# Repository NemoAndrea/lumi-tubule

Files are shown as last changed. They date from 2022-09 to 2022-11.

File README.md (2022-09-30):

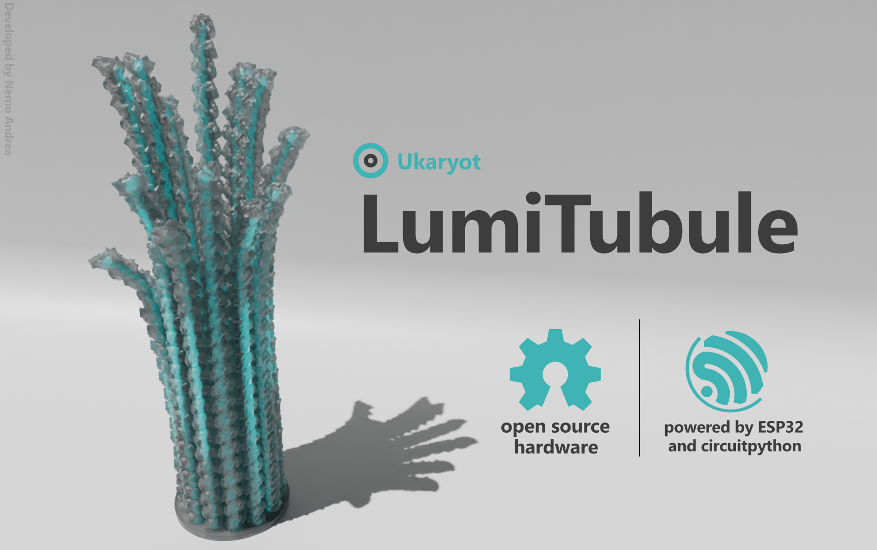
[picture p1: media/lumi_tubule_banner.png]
lumi tubule promo image


> **warning** 🚧 Under Construction - There is still a lot of work to be done on this project. Have a look at issues if you want to contribute (e.g. review PCB) or check back later when the project is getting closer to release 👷

## LumiTubule - open hardware decorative led sculpture

LumiTubule is a simple decorative lamp in the shape of a [microtubule]() that can be programmed to respond to events (e.g. emails). While primarily decorative, the PCB comes with a temperature and humidity sensor and a basic accelerometer for user interaction - and a stemma QT port in case you want to add more sensors!

It's all powered by a small USB-C power supply, so it barely takes up any desk space.

The PCB design, 3D printable files and bill of materials are all available, so you can put together your own LumiTubule. If you would like to have one, but would rather not go through the assembly process, you can get in touch. 

### Components

There are 4 key components that make up the LumiTubule

1. The custom PCB with ESP32 microcontroller and onboard sensors
2. A [15W USB-C power supply](https://www.raspberrypi.com/products/type-c-power-supply/)
3. The 3D printed microtubule sculpture (translucent)
4. The 13 flexible LED filaments that sit inside the sculpture

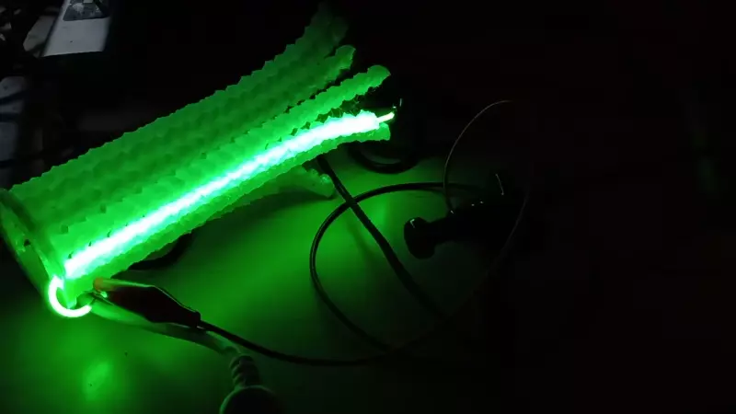
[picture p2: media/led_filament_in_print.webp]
led filaments in action


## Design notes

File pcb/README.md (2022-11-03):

### LumiTubule PCB

The LumiTubule PCB is generated with KiCad 6.0

The following plugins were used:

* [Teardrops plugin](https://github.com/NilujePerchut/kicad_scripts/tree/master/teardrops) (manual install - in PCBnew go to `tools` > `external plugins` > `open plugin directory`) 
* [Rounded tracks plugin](https://github.com/mitxela/kicad-round-tracks) (via plugin manager)

### Graphics

The graphics for the board are primarily created in Affinity Designer, with the help of [Inkscape](https://inkscape.org/) for some of the outline traces and image binarisation.

Some weird quirks during drawing process

- KiCad seems really picky about when it will render the hole in the board. The outline of the board has a lot of polygons. I am not sure what property of the inner circle makes it work better, but be aware that some frustrations may occur here if you try to change it.

### Considerations

> **Note** The points below provide some insight into why certain parts were selected. If you spot any errors in the calculations or reasoning, feel free to let me know!

**LED filament current limiting resistor value**

The LED filaments can handle about 100mA current (more in practice seems fine), so let's aim for that value. 

We start with a 5V supply.  These kind of LED filaments [have been reported to drop around 2.56V](https://www.brickstuff.com/store/p198/flexfilament.html), which is consistent with measurements done on a test rig. They seem to all use blue LEDs underneath, so that is a pretty safe maximum drop. The `DMN1045UFR4` MOSFET has a typical R_DSon between 25-32mΩ at 3.3V V_GS according to the datasheet. The voltage drop over the MOSFET will be 0.1A*25mΩ = 2.5mV. We can safely ignore that value. Our resistor value should then be (Vsup - V_LED)/I_LED = (5-2.56) / 0.1 = 24Ω. Let's play it safe and get something slightly higher: 27Ω. 

We then dissipate `P = I^2 * R  = 0.1^2 * 27 = 270mW` in the current limiting resistor. At max power on all 13 filaments this is 13*0.27=3.5W, quite a bit of power. Given that it is a worst-case scenario, it should be acceptable.

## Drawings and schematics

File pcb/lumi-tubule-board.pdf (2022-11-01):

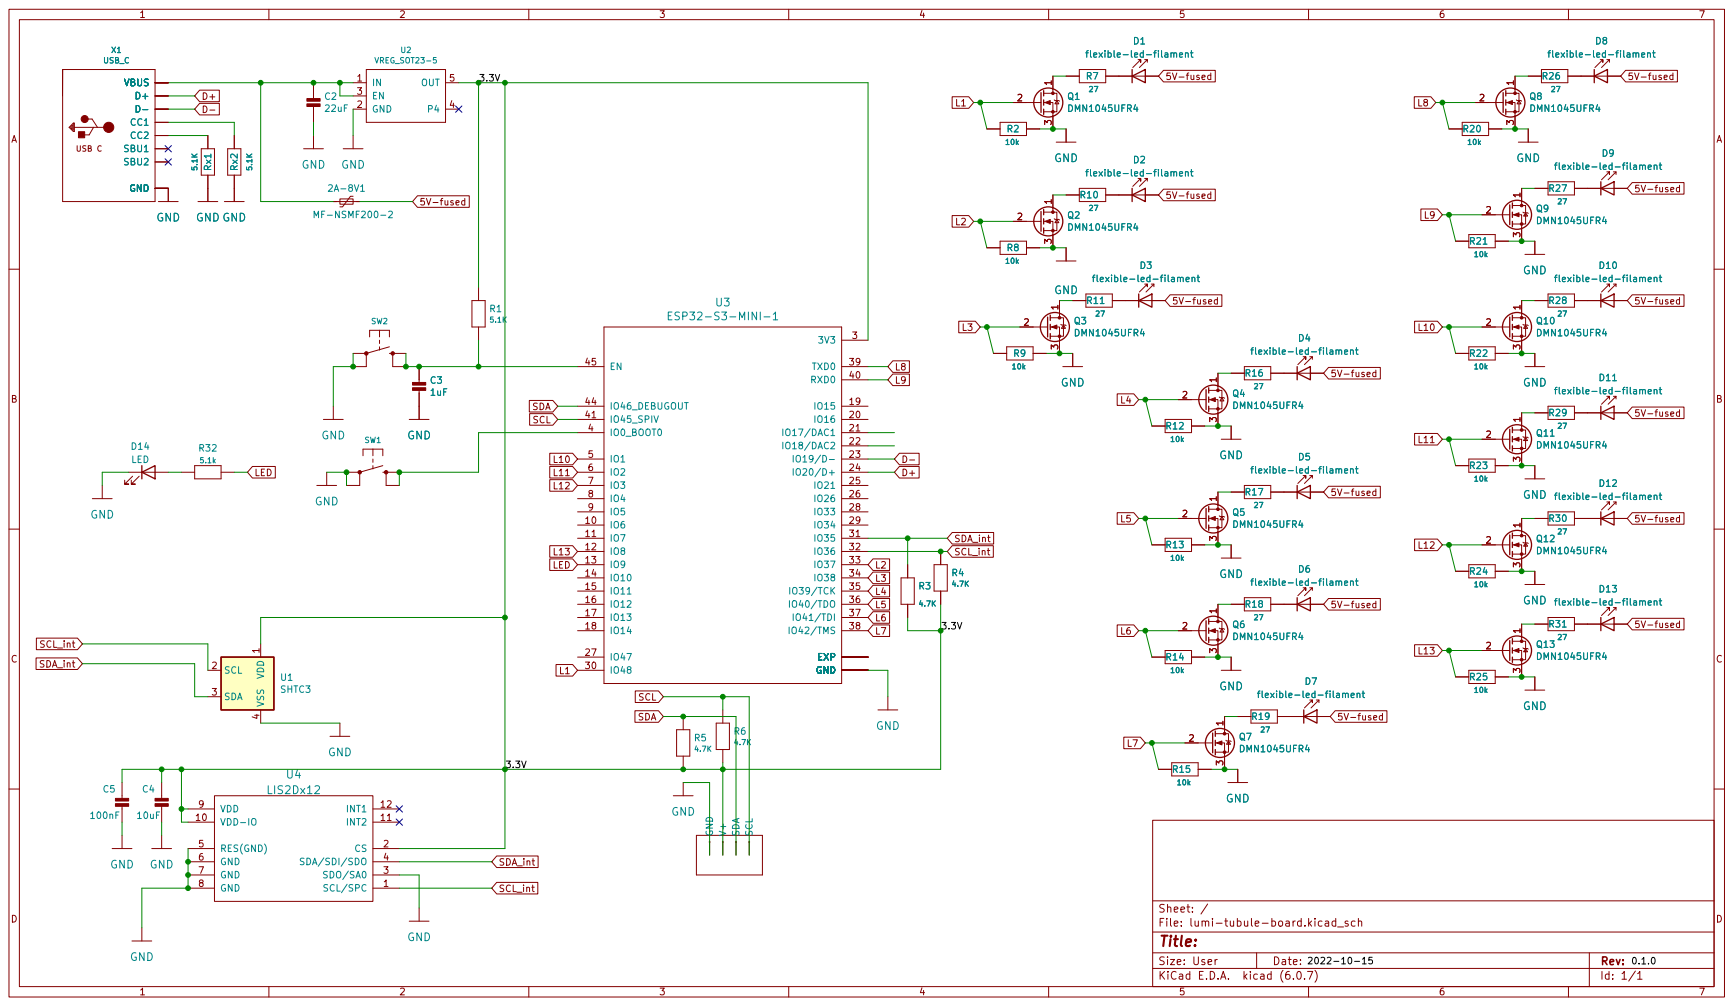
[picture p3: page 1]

flexible-led-filament VDD

3 Q11 DMN1045UFR4 GND D11
flexible-led-filament GND
flexible-led-filament R29

flexible-led-filament R17

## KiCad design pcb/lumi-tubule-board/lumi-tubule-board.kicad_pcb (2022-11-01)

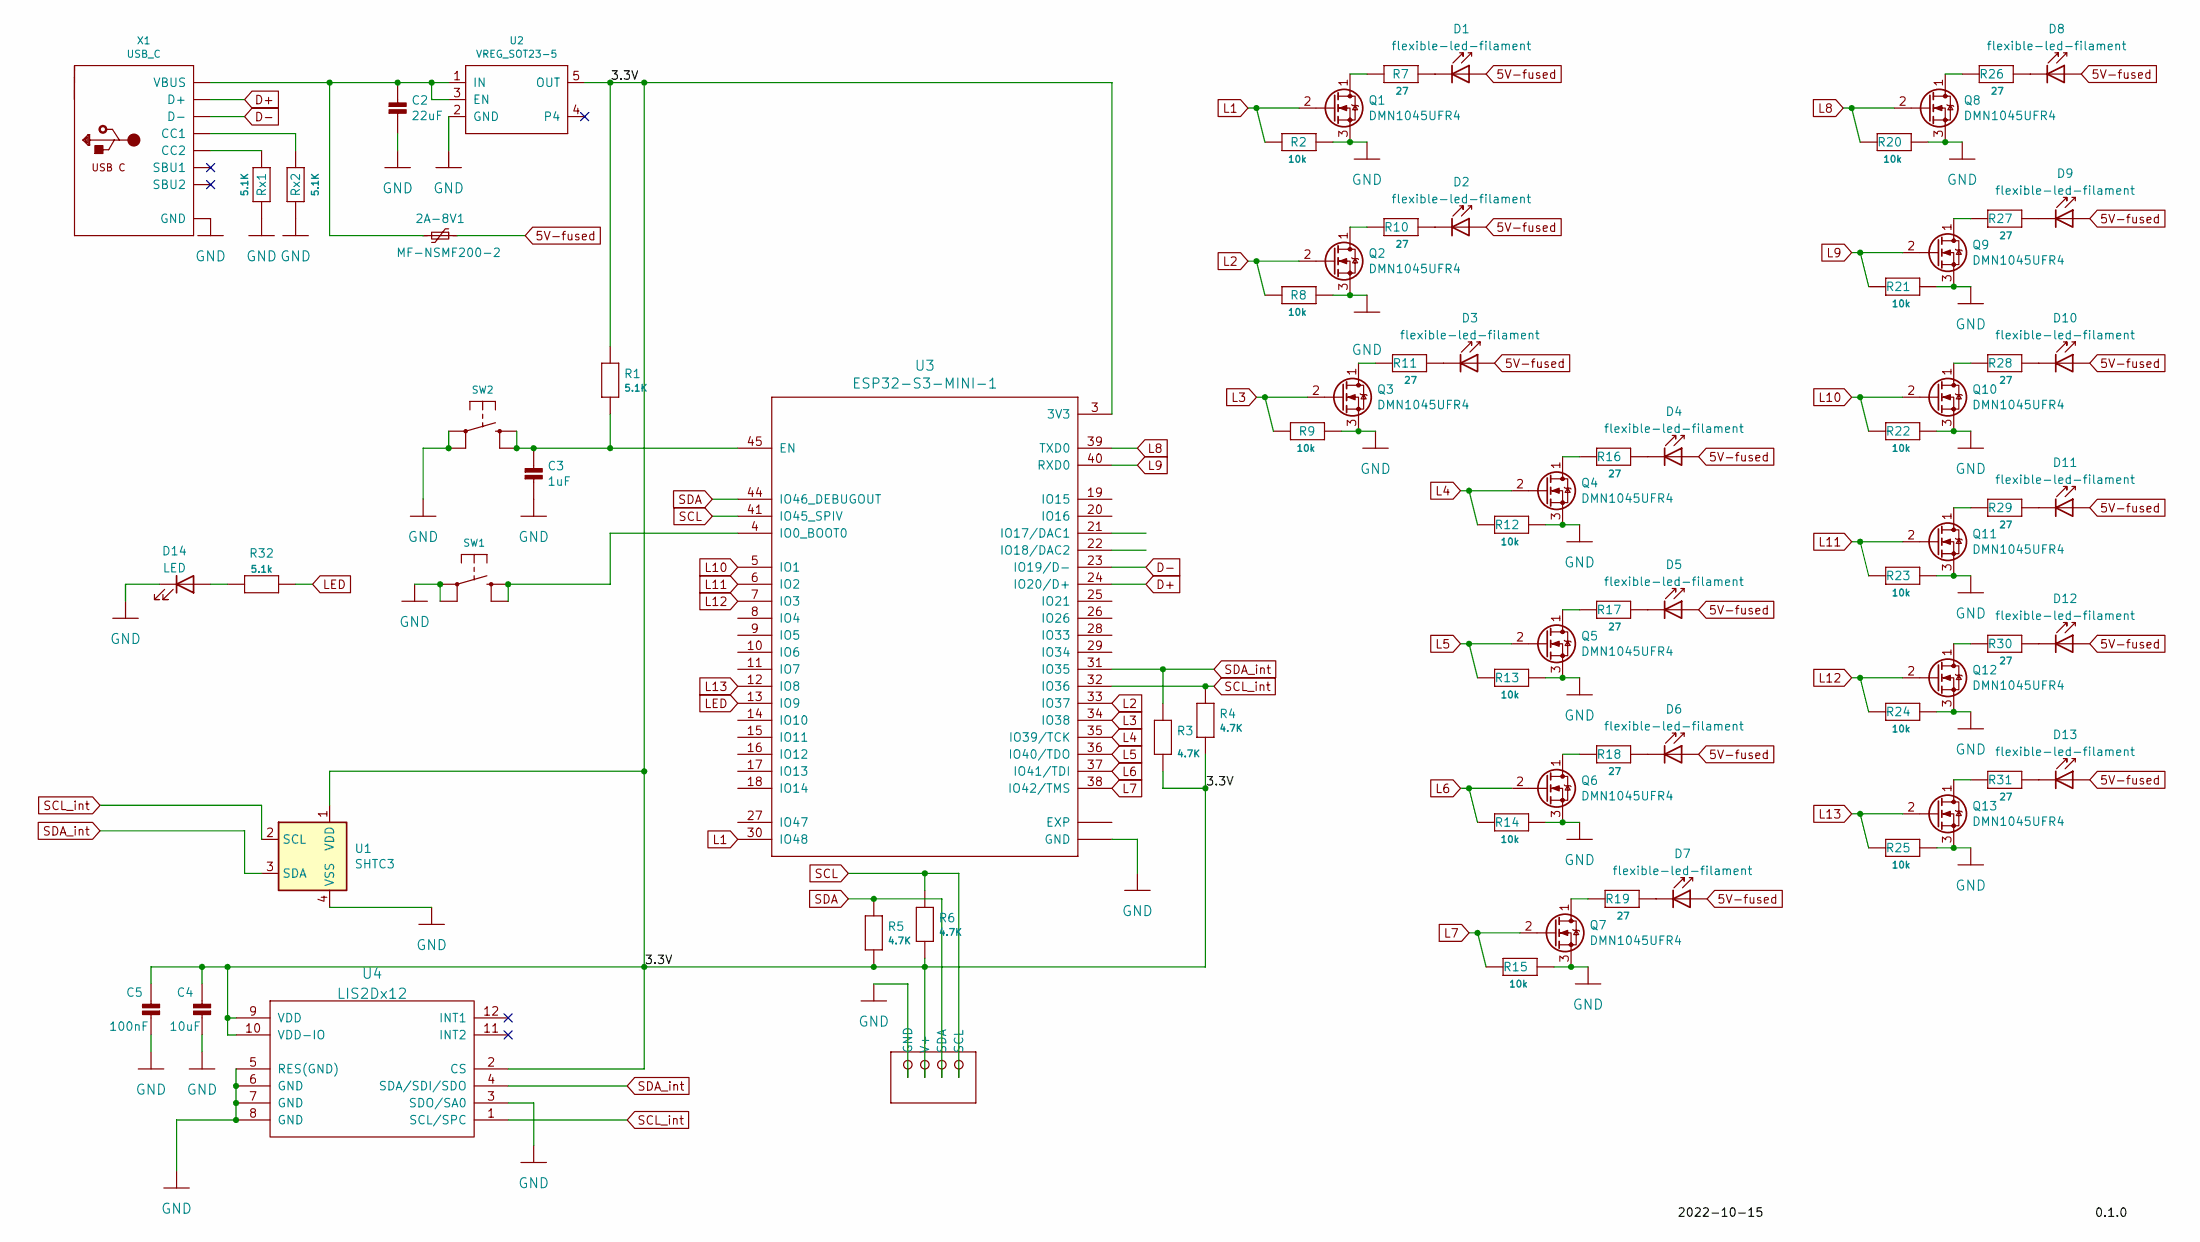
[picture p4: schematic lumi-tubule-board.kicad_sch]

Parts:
2A-8V1: MF-NSMF200-2
C2: 22uF; C_0603_1608Metric
C3: 1uF; C_1206_3216Metric; JLCPCB ref C1848
C4: 10uF; C_0805_2012Metric; JLCPCB ref C440198
C5: 100nF; C_0402_1005Metric; JLCPCB ref C307331
CONN1: STEMMA_I2C_QTSKINNY; JST_SH_BM04B-SRSS-TB_1x04-1MP_P1.00mm_Vertical; JLCPCB ref C160390
D1, D2, D3, D4, D5, D6, D7, D8, D9, D10, D11, D12, D13: flexible-led-filament; Flexible LED filament viamount
D14: LED; LED_0603_1608Metric; JLCPCB ref C72043
Q1, Q2, Q3, Q4, Q5, Q6, Q7, Q8, Q9, Q10, Q11, Q12, Q13: DMN1045UFR4; JLCPCB ref C460988
R1: 5.1K; R_0805_2012Metric
R2, R8, R9, R12, R13, R14, R15, R20, R21, R22, R23, R24, R25: 10k; R_0402_1005Metric; JLCPCB ref C25744
R3, R4, R5, R6: 4.7K; R_0603_1608Metric; JLCPCB ref C23162
R7, R10, R11, R16, R17, R18, R19, R26, R27, R28, R29, R30, R31: 27; R_0805_2012Metric; JLCPCB ref C966124
R32: 5.1k; R_0603_1608Metric; JLCPCB ref C22961
Rx1, Rx2: 5.1K; R_0805_2012Metric
SW1, SW2: SWITCH_TACT_SMT4.6X2.8; BTN_KMR2_4.6X2.8
U1: SHTC3; Sensirion_DFN-4-1EP_2x2mm_P1mm_EP0.7x1.6mm; JLCPCB ref C194656
U2: VREG_SOT23-5; SOT-23-5; JLCPCB ref C176944
U3: ESP32-S3-MINI-1; ESP32-S2-MINI-1; JLCPCB ref C2913206
U4: LIS2Dx12; LGA-12_2x2mm_P0.5mm; JLCPCB ref C110926
X1: USB_C; USB_C_Receptacle_HRO_TYPE-C-31-M-12

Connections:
5V-fused: 2A-8V1.1, D1.2 (A), D2.2 (A), D3.2 (A), D4.2 (A), D5.2 (A), D6.2 (A), D7.2 (A), D8.2 (A), D9.2 (A), D10.2 (A), D11.2 (A), D12.2 (A), D13.2 (A)
/3.3V: C4.2, C5.2, CONN1.2 (V+), R1.1, R3.2, R4.2, R5.2, R6.2, U1.1 (VDD), U2.5 (OUT), U3.3 (3V3), U4.2 (CS), U4.9 (VDD), U4.10 (VDD-IO)
D+: U3.24 (IO20/D+), X1.A6 (D+), X1.B6 (D+)
D-: U3.23 (IO19/D-), X1.A7 (D-), X1.B7 (D-)
GND: C2.2, C3.2, C4.1, C5.1, CONN1.1 (GND), D14.1 (K), Q1.3 (Source), Q2.3 (Source), Q3.3 (Source), Q4.3 (Source), Q5.3 (Source), Q6.3 (Source), Q7.3 (Source), Q8.3 (Source), Q9.3 (Source), Q10.3 (Source), Q11.3 (Source), Q12.3 (Source), Q13.3 (Source), R2.1, R8.1, R9.1, R12.1, R13.1, R14.1, R15.1, R20.1, R21.1, R22.1, R23.1, R24.1, R25.1, Rx1.2, Rx2.2, SW1.A, SW1.A' (P1), SW2.A, SW2.A' (P1), U1.4 (VSS), U2.2 (GND), U3.1 (GND), U3.2 (GND), U3.42 (GND), U3.43 (GND), U3.46 (GND), U3.47 (GND), U3.48 (GND), U3.49 (GND), U3.50 (GND), U3.51 (GND), U3.52 (GND), U3.53 (GND), U3.54 (GND), U3.55 (GND), U3.56 (GND), U3.57 (GND), U3.58 (GND), U3.59 (GND), U3.60 (GND), U3.62 (GND), U3.63 (GND), U3.64 (GND), U3.65 (GND), U4.3 (SDO/SA0), U4.5 (RES(GND)), U4.6 (GND), U4.7 (GND), U4.8 (GND), X1.A1 (GND), X1.A12 (GND), X1.B1 (GND), X1.B12 (GND)
L1: Q1.2 (Gate), R2.2, U3.30 (IO48)
L2: Q2.2 (Gate), R8.2, U3.33 (IO37)
L3: Q3.2 (Gate), R9.2, U3.34 (IO38)
L4: Q4.2 (Gate), R12.2, U3.35 (IO39/TCK)
L5: Q5.2 (Gate), R13.2, U3.36 (IO40/TDO)
L6: Q6.2 (Gate), R14.2, U3.37 (IO41/TDI)
L7: Q7.2 (Gate), R15.2, U3.38 (IO42/TMS)
L8: Q8.2 (Gate), R20.2, U3.39 (TXD0)
L9: Q9.2 (Gate), R21.2, U3.40 (RXD0)
L10: Q10.2 (Gate), R22.2, U3.5 (IO1)
L11: Q11.2 (Gate), R23.2, U3.6 (IO2)
L12: Q12.2 (Gate), R24.2, U3.7 (IO3)
L13: Q13.2 (Gate), R25.2, U3.12 (IO8)
LED: R32.2, U3.13 (IO9)
unnamed: 2A-8V1.2, C2.1, U2.1 (IN), U2.3 (EN), X1.A4 (VBUS), X1.A9 (VBUS), X1.B4 (VBUS), X1.B9 (VBUS)
unnamed: C3.1, R1.2, SW2.B (S), SW2.B' (S1), U3.45 (EN)
unnamed: D1.1 (K), R7.1
unnamed: D2.1 (K), R10.1
unnamed: D3.1 (K), R11.1
unnamed: D4.1 (K), R16.1
unnamed: D5.1 (K), R17.1
unnamed: D6.1 (K), R18.1
unnamed: D7.1 (K), R19.1
unnamed: D8.1 (K), R26.1
unnamed: D9.1 (K), R27.1
unnamed: D10.1 (K), R28.1
unnamed: D11.1 (K), R29.1
unnamed: D12.1 (K), R30.1
unnamed: D13.1 (K), R31.1
unnamed: D14.2 (A), R32.1
unnamed: Q1.1 (Drain), R7.2
unnamed: Q2.1 (Drain), R10.2
unnamed: Q3.1 (Drain), R11.2
unnamed: Q4.1 (Drain), R16.2
unnamed: Q5.1 (Drain), R17.2
unnamed: Q6.1 (Drain), R18.2
unnamed: Q7.1 (Drain), R19.2
unnamed: Q8.1 (Drain), R26.2
unnamed: Q9.1 (Drain), R27.2
unnamed: Q10.1 (Drain), R28.2
unnamed: Q11.1 (Drain), R29.2
unnamed: Q12.1 (Drain), R30.2
unnamed: Q13.1 (Drain), R31.2
unnamed: Rx1.1, X1.B5 (CC2)
unnamed: Rx2.1, X1.A5 (CC1)
unnamed: SW1.B (S), SW1.B' (S1), U3.4 (IO0_BOOT0)
unnamed: U3.61 (EXP), U3.66 (EXP), U3.67 (EXP), U3.68 (EXP), U3.69 (EXP), U3.70 (EXP), U3.71 (EXP), U3.72 (EXP), U3.73 (EXP)
SCL: CONN1.4 (SCL), R6.1, U3.41 (IO45_SPIV)
SCL_int: R4.1, U1.2 (SCL), U3.32 (IO36), U4.1 (SCL/SPC)
SDA: CONN1.3 (SDA), R5.1, U3.44 (IO46_DEBUGOUT)
SDA_int: R3.1, U1.3 (SDA), U3.31 (IO35), U4.4 (SDA/SDI/SDO)

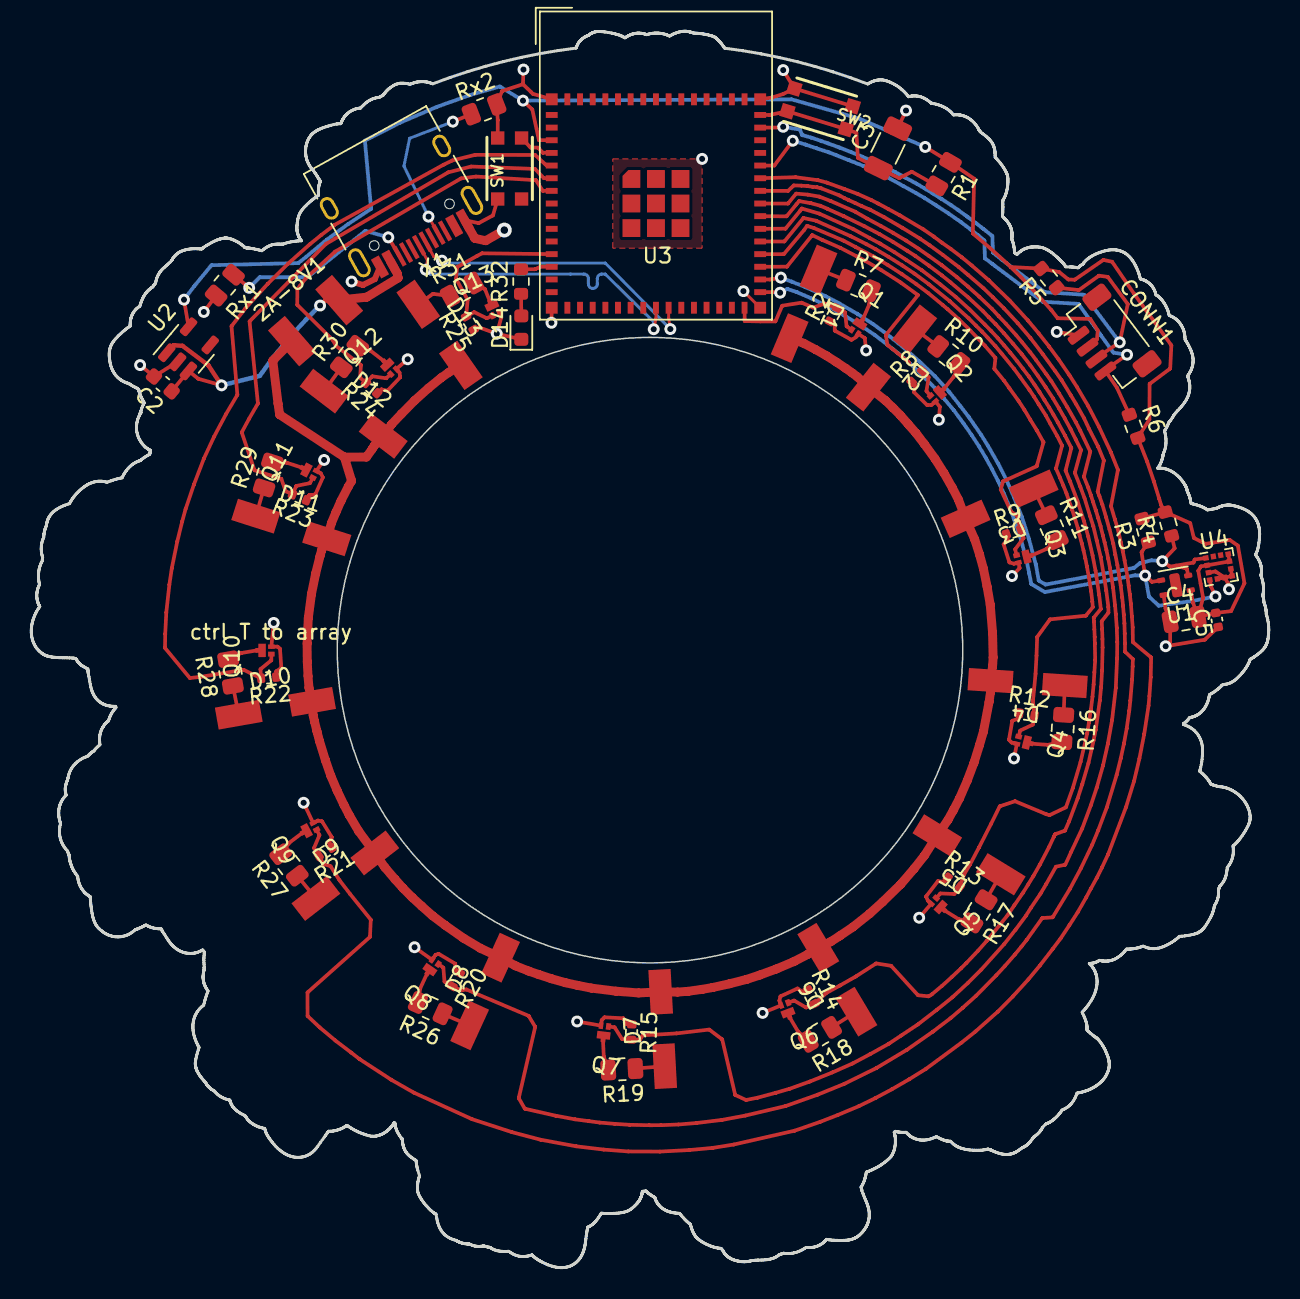
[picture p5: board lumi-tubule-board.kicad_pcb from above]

Board: 2 copper layers, 83.1 x 83.0 mm, 74 parts (0 on the bottom side), 55 nets.

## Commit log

2022-09-20 Initial PCB version
    First version of kicad 6.0 PCB. All footprints loaded, but there are still some connection errors to be sorted out.
    [lumi-tubule-board.kicad_pcb, lumi-tubule-board.kicad_sch]
2022-09-23 Fix schematic footprint issues
    Fixed footprint errors in pcbnew. Initial exploration of layout. Fixed typo in banner.
    [lumi-tubule-board.kicad_pcb, lumi-tubule-board.kicad_sch]
2022-09-30 PCB design update
    Added LIS2DH12 accelerometer to PCB. Reworked the filament pads. Fixed footprints. Added pullup resistors to I2C lines. Started planning the layout in more compact footprint.
    [lumi-tubule-board.kicad_pcb, lumi-tubule-board.kicad_sch]
2022-10-01 First wiring for PCB
    First fully wired up arrangement for PCB. It's not pretty and the differential pairs are not good yet and the schematic still needs updating.
    [lumi-tubule-board.kicad_pcb]
2022-10-15 Revise PCB
    - fixed backwards USB port
    - redo power routing
    - make I2C lines cleaner
    - make differential lines length matched
    [lumi-tubule-board.kicad_pcb, lumi-tubule-board.kicad_sch]
2022-10-18 Add LED and fix pad numbers
    Add low power LED to board and fix some missing links between schematic and pcb design.
    [lumi-tubule-board.kicad_pcb, lumi-tubule-board.kicad_sch]
2022-10-22 Move to ground plane approach
    Opt to go for ground plane design and forgo extra PCB art colour. Simplifies a lot of things. Currently I2C lines still need to be wired up and some traced cleaned up.
    [lumi-tubule-board.kicad_pcb]
2022-10-23 Correct and complete traces
    Redid ugly traces and connected SDA/SCL lines to new ground plane design.
    [lumi-tubule-board.kicad_pcb]
2022-11-01 Fix MOSFET wiring
    Fixed the MOSFETs' wiring, which was all wrong. Rerouted mosfet out via ground plane, freeing up space for the Vsup line on top of board. Removed the diagnosis LED line on the back of PCB which was interrupting ground plane flow. Swapped out the pulldown resistor for something smaller.
    [lumi-tubule-board.kicad_pcb, lumi-tubule-board.kicad_sch]
2022-11-03 Add board graphics
    Added main backside graphics as well as open hardware logos and metadata text
